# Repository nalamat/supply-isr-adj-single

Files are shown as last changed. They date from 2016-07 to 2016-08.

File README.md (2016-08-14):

# supply-isr-adj-single
Integrated switching adjustable single power supply based on TI TPS54232

## Application notes
Input voltage range: 3.5 to 28v  
Output voltage range: 0.8 to 25v in steps of 0.1v  
Maximum output current: 2A  
Normally off, turns on by shorting EN pin header to On  
Output is also adjustable using shorting jumpers on Vadj pin header  
Output voltage is calculated by sum of all shorted headers plus 0.8v  
LED is an indicator of input power supply, not output

## License
Licensed under GPLv3  
Copyright 2016 NESH@NJIT

Neural Engineering of Speech and Hearing  
New Jersey Institute of Technology  
http://centers.njit.edu/nesh

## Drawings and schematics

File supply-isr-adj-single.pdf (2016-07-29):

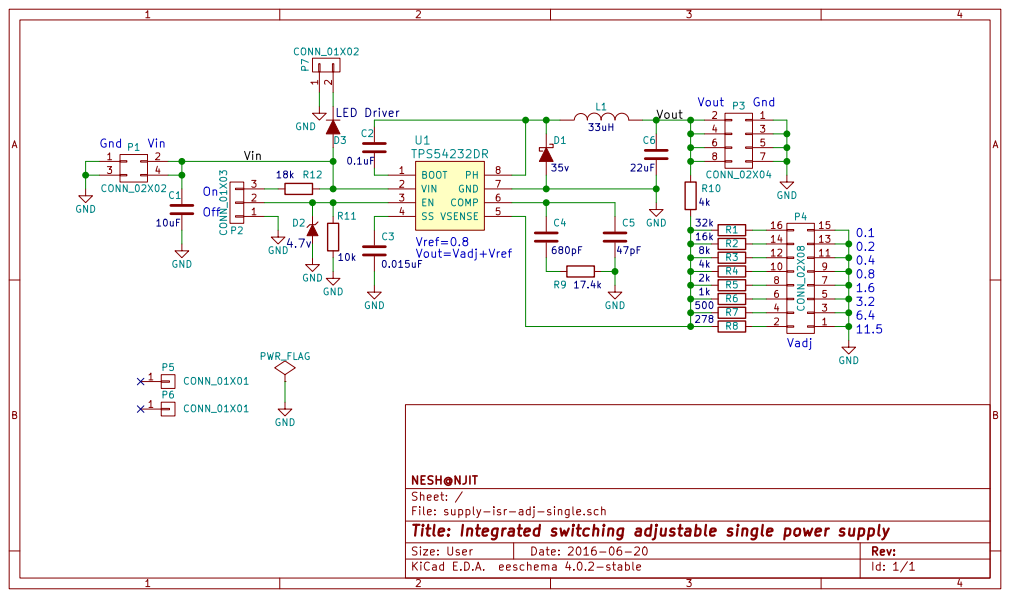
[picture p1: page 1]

File: supply-isr-adj-single.sch Sheet: / NESH@NJIT

Id: 1/1 Title: Integrated switching adjustable single power supply

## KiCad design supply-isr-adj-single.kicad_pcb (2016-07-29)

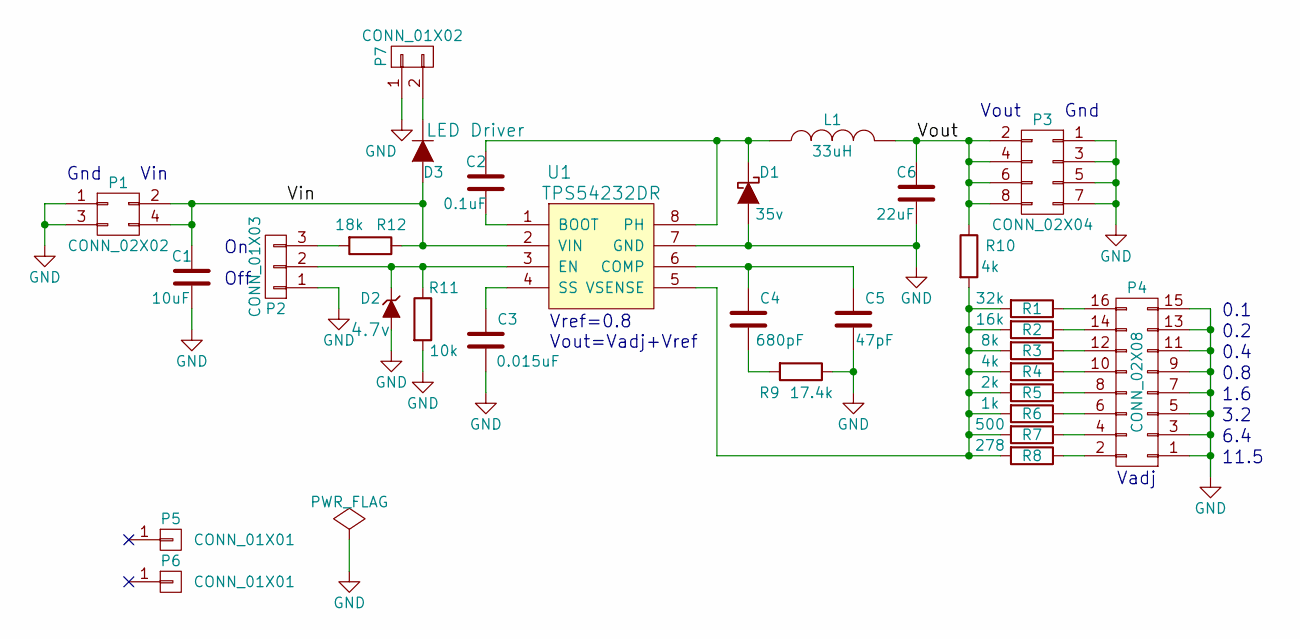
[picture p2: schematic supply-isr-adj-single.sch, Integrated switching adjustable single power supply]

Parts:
C1: GRM319R6YA106KA12D; C_1206
C2: GRM188R71E104KA01D; C_0603
C3: GRM155R71H153KA12J; C_0402
C4: CL05B681KB5NNNC; C_0402
C5: C0805C470KCRACTU; C_0805
C6: GRM31CR61E226KE15L; C_1206
D1: DB2W40200L; SOD-123
D2: DZ2J047M0L; SOD-323
D3: NSI45015WT1G; SOD-123
L1: SRP1038A-330M; SRP1038A
P1: CONN_02X02; Pin_Header_Straight_2x02
P2: CONN_01X03; Pin_Header_Straight_1x03
P3: CONN_02X04; Pin_Header_Straight_2x04
P4: CONN_02X08; Pin_Header_Straight_2x08
P5, P6: CONN_01X01; 1pin
P7: CONN_01X02; Pin_Header_Straight_1x02
R1: RC0402FR-0731K6L; R_0402
R2: RC0402FR-0716K2L; R_0402
R3: RC0805FR-078K06L; R_0805
R4, R10: RC0603FR-074K02L; R_0603
R5: RC0805FR-072KL; R_0805
R6: RC0402JR-071KL; R_0402
R7: ERJ-2RKF4990X; R_0402
R8: RC0402FR-07280RL; R_0402
R9: RC0402FR-0717K4L; R_0402
R11: RC0402JR-0710KL; R_0402
R12: RC0603FR-0717K8L; R_0603
U1: TPS54232DR; SOIC-8-N

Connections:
/Vin: C1.1, D3.2 (A), P1.2, P1.4, R12.1, U1.2 (VIN)
/Vout: C6.1, L1.2, P3.2, P3.4, P3.6, P3.8, R10.1
GND: C1.2, C3.2, C5.2, C6.2, D1.2 (A), D2.2 (A), P1.1, P1.3, P2.1, P3.1, P3.3, P3.5, P3.7, P4.1, P4.3, P4.5, P4.7, P4.9, P4.11, P4.13, P4.15, P7.1, R9.1, R11.2, U1.7 (GND)
unnamed: C2.1, D1.1 (K), L1.1, U1.8 (PH)
unnamed: C2.2, U1.1 (BOOT)
unnamed: C3.1, U1.4 (SS)
unnamed: C4.1, C5.1, U1.6 (COMP)
unnamed: C4.2, R9.2
unnamed: D2.1 (K), P2.2, R11.1, U1.3 (EN)
unnamed: D3.1 (K), P7.2
unnamed: P2.3, R12.2
unnamed: P4.2, R8.1
unnamed: P4.4, R7.1
unnamed: P4.6, R6.1
unnamed: P4.8, R5.1
unnamed: P4.10, R4.1
unnamed: P4.12, R3.1
unnamed: P4.14, R2.1
unnamed: P4.16, R1.1
unnamed: R1.2, R2.2, R3.2, R4.2, R5.2, R6.2, R7.2, R8.2, R10.2, U1.5 (VSENSE)

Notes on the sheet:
Vin
Gnd
Off
Vout
0.1
0.2
0.4
0.8
1.6
3.2
6.4
11.5
Vadj
Vref=0.8 Vout=Vadj+Vref

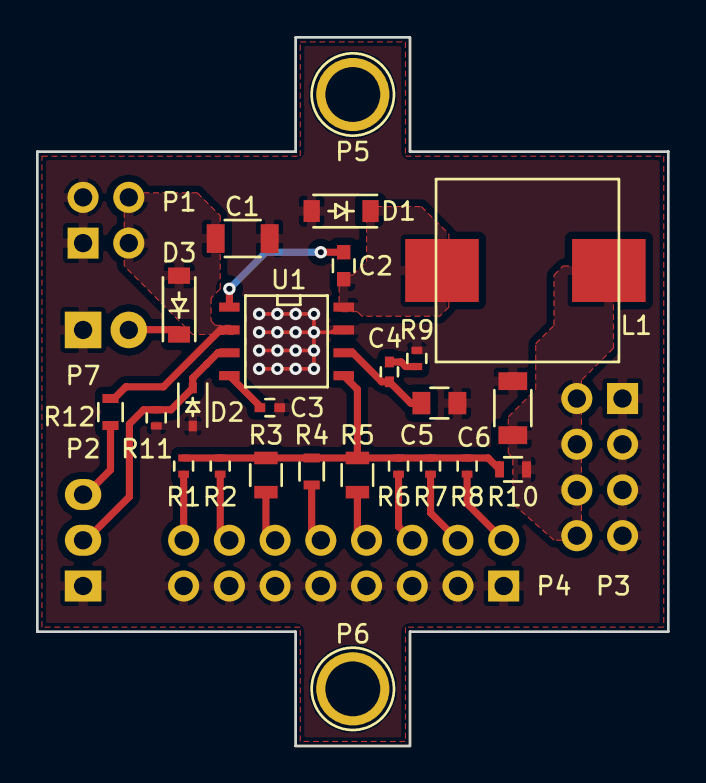
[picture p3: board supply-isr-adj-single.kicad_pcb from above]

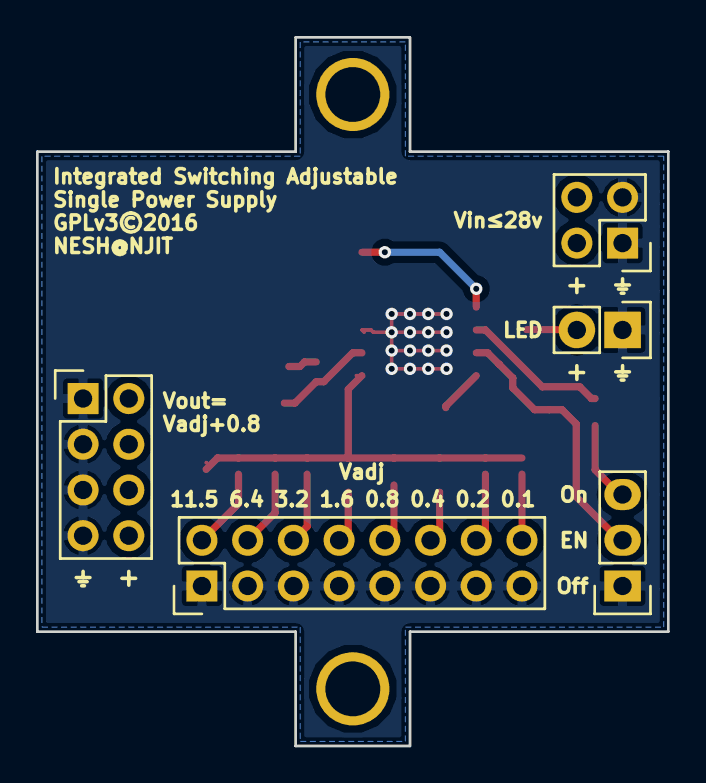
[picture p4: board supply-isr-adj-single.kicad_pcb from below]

Board: 2 copper layers, 35.1 x 39.4 mm, 30 parts (5 on the bottom side), 20 nets.

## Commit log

2016-06-21 Clean up
    [supply-isr-adj-single.sch]
2016-06-21 Add schematic PDF
2016-06-24 Create footprint for SMD inductor
2016-06-24 Finalize schematic
    [supply-isr-adj-single.sch]
2016-06-24 Finalize PCB
    [supply-isr-adj-single.kicad_pcb]
2016-06-24 Add gerber plots
    [supply-isr-adj-single-B.Cu.gbl, supply-isr-adj-single-B.Mask.gbs, supply-isr-adj-single-B.Paste.gbp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]
2016-06-29 Update schematic PDF
2016-07-29 Limit EN pin voltage Add LED port
    [supply-isr-adj-single-B.Cu.gbl, supply-isr-adj-single-B.Mask.gbs, supply-isr-adj-single-B.Paste.gbp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]

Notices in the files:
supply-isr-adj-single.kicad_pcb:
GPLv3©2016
